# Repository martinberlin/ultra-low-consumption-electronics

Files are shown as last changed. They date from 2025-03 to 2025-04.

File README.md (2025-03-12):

# ultra-low-consumption-electronics
Here we will make electronic experiments to try reaching the lowest possible consumption when dealing with Microcontrollers and small Lithium batteries, turning when possible everything OFF

## Parts will be a shared folder between different PCBs

The parts folder will contain common Symbols, Footprints and 3D models.

## 1st. experiment: RV3032 application manual page 144

RV3032 is a DTCXO Temp. Compensated Real-Time Clock Module
Based on App. Manual released on May 2023 144/154 Rev. 1.3

**8.5. NO BACKUP SOURCE / EVENT INPUT USED ("WAKE-UP" & "POWER SWITCH")**

#f03c15WARNING:#f03c15
 This are theoretical ideas that could mainly be untested. Use any of them on production at your own risk.

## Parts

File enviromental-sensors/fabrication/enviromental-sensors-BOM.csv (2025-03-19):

Designator | Footprint | Comment | JLCPCB Part #
J1 | USB_C_Receptacle_HRO_TYPE-C-31-M-12 | USB_C_Receptacle_USB2.0 | C165948
C2,C8,C7,C1 | C_0805_2012Metric | 10uF | C15850
Y1 | RV3032C7 | RV-3032-C7 | C5127802
R5 | R_0603_1608Metric | 1k | C21190
SW4,SW2,SW1 | C2845289_SW-SMD_4P-L5.2-W5.2-P3.70-LS6.4 | TC-0522C-1.7-160G | C2845289
U6 | SOT-89-3 | L78L33ACUTR | C14170
J3 | FH5210S05SH99_LCD | FH52-10S-0.5SH_99 | C598038
R2,R12,R8,R3 | R_0603_1608Metric | 5.1k | C23186
R1,R10,R7 | R_0603_1608Metric | 10K | C25804
Q1 | SOT-23 | AO3401A | C15127
U5 | Sensirion_SCD4x-1EP_10.1x10.1mm_P1.25mm_EP4.8x4.8mm | SCD40-D-R2 | C3659421
U4 | C3001660_SOT95P285X140-5N | AP22811 | C3001660
U2 | SOT-23-5 | RT9080 | C841192
R9 | R_0603_1608Metric | 2K | C22975
D1 | D_SOD-123 | Schottky | C8598
IC2 | C22399676_TPS2117-8N | TPS2117DRLR | C22399676
C3 | C_0402_1005Metric | 1uF | C162161
C4 | C_0402_1005Metric | 22pF | C5119318
SW3 | C5143621_KEY-SMD_TS24ZJ | K2-1806SQ-A2DW-04 | C19100323
C5 | C_0805_2012Metric | 100nF | C49678
R14 | R_0603_1608Metric | 0Ω | C21189
R4,R6 | R_0402_1005Metric | 10k | C4322213
J2 | S2BPHSM4TBLFSN | S2B-PH-SM4-TB_LF__SN_ | C295747
C9 | CP_EIA-3528-15_AVX-H | 100uF | C16133
R13 | R_0603_1608Metric | 0Ω | C21189
R11 | R_0603_1608Metric | 10k | C25804
U1 | SOT-666 | USBLC6-2P6 | C2827693
Q2 | TEMT6000X01 | TEMT6000X01 | C94098
J5 | SM04B-SRSS-TB_LF__SN_ | JST connector | C160404

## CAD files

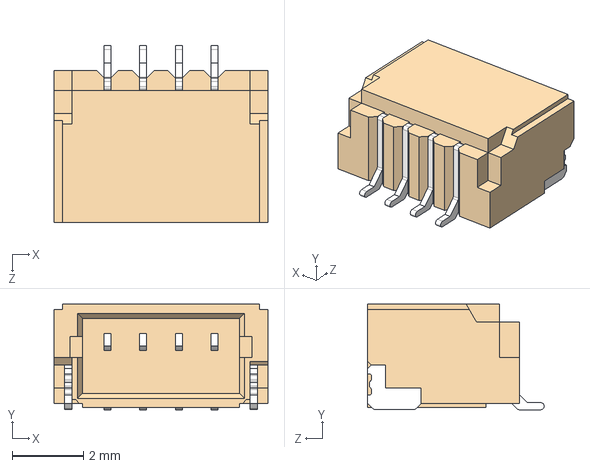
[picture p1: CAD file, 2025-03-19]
enviromental-sensors/parts/3D/QWIIC_SM04B-SRSS-TB_LF__SN_.stp
6.00 x 2.96 x 4.95 mm

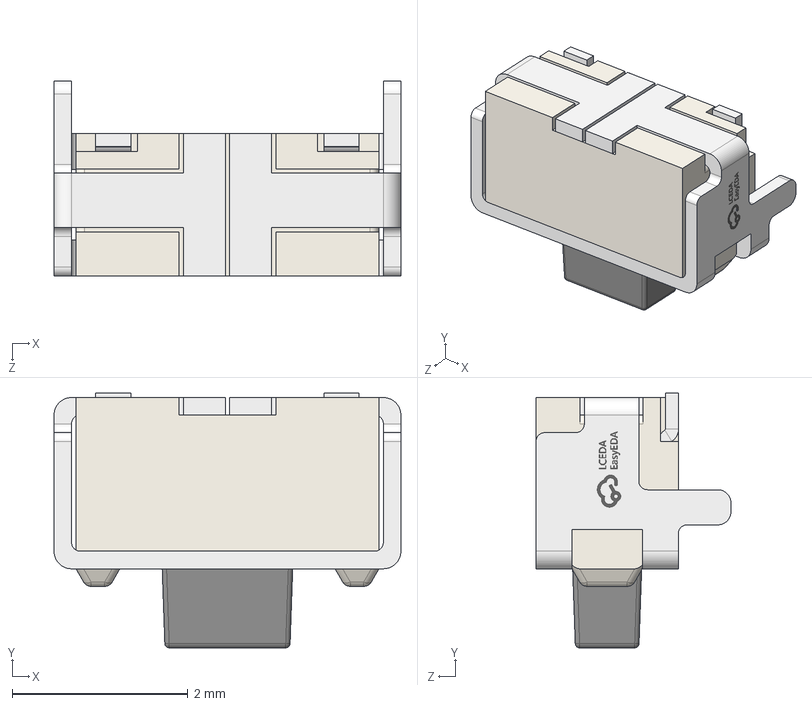
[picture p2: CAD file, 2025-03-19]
enviromental-sensors/parts/3D/KEY-SMD_K2_L4.0-W2.9-H1.6-P3.75.step
3.95 x 2.90 x 2.22 mm

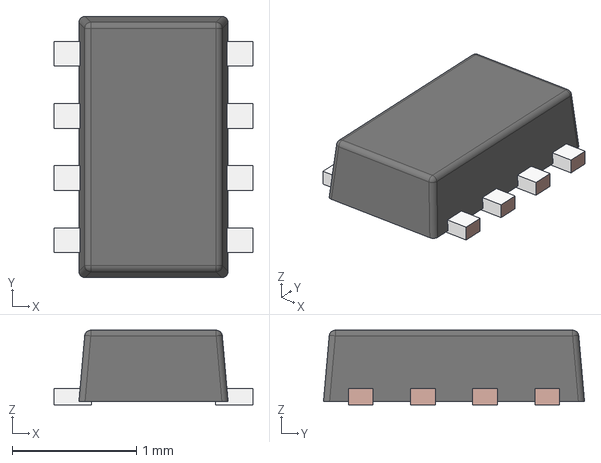
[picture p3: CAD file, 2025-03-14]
parts/3D/TPS2117DRLR.stp
1.60 x 2.10 x 0.6 mm
FRAME-DRL0008A
BODY-SOT

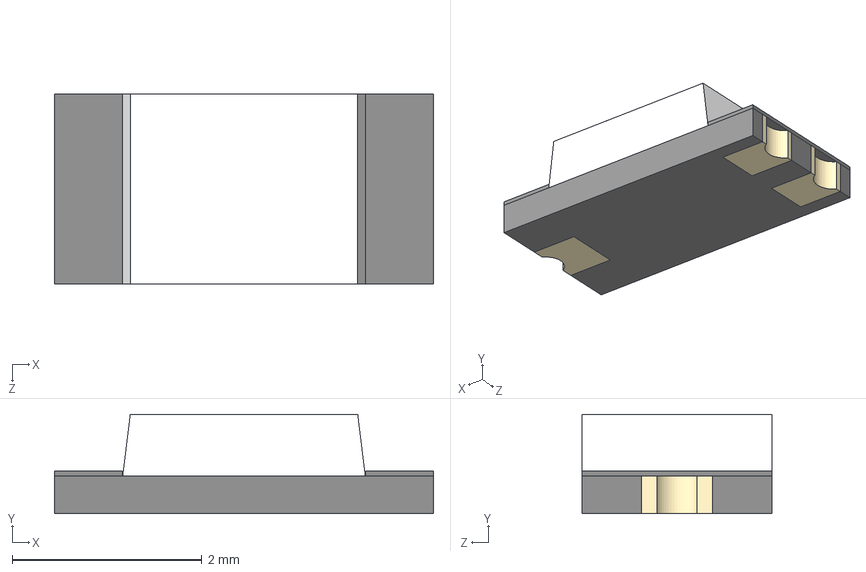
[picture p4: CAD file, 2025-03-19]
enviromental-sensors/parts/3D/TEMT6000X01.stp
4.00 x 1.05 x 2.00 mm

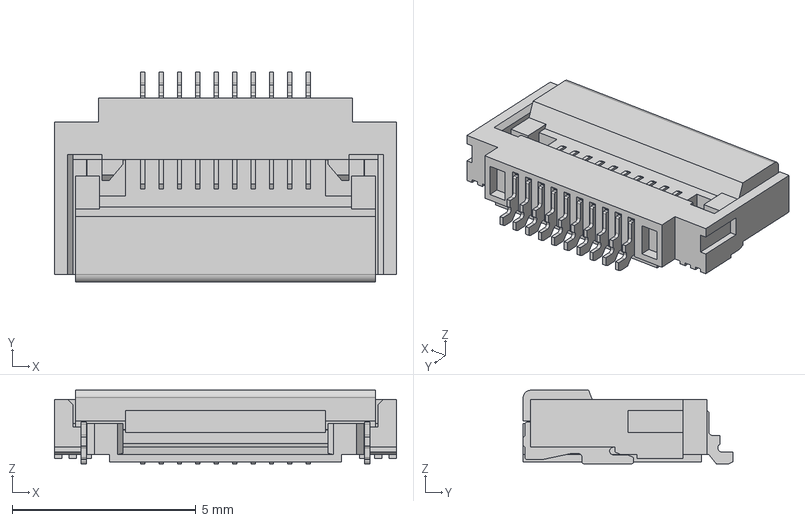
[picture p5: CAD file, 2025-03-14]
parts/3D/LCD-10S-0.5SH.step
9.30 x 5.70 x 2.00 mm

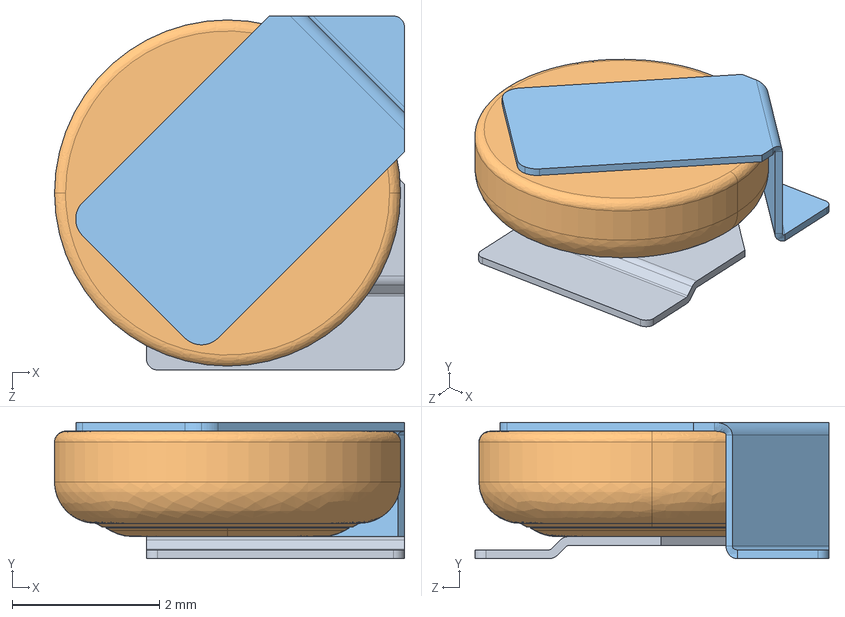
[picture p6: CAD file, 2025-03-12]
parts/3D/SuperCAP_XH414HG-IV01E.stp
4.75 x 1.85 x 4.80 mm

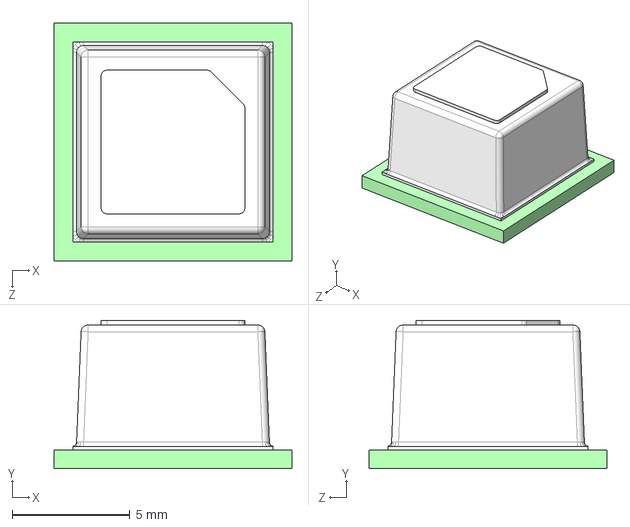
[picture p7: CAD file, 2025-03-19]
enviromental-sensors/parts/3D/SCD40-D-R2.stp
10.1 x 6.30 x 10.1 mm

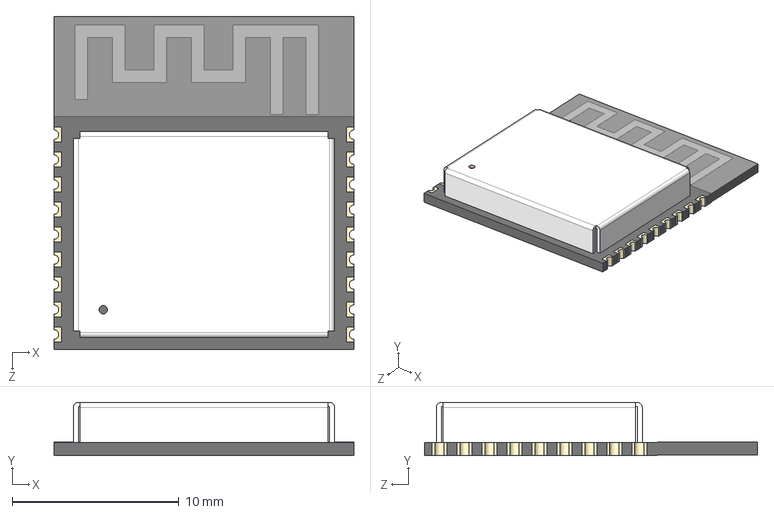
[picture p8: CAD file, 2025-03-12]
parts/3D/ESP32-C3-WROOM-02-N4.stp
18.0 x 3.20 x 20.0 mm

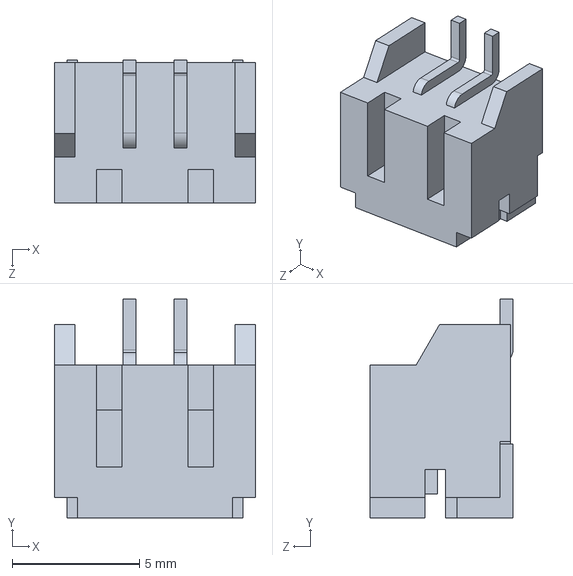
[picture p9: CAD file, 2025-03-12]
parts/3D/S2B-PH-SM4-TB_LF__SN_.stp
7.90 x 8.60 x 5.60 mm

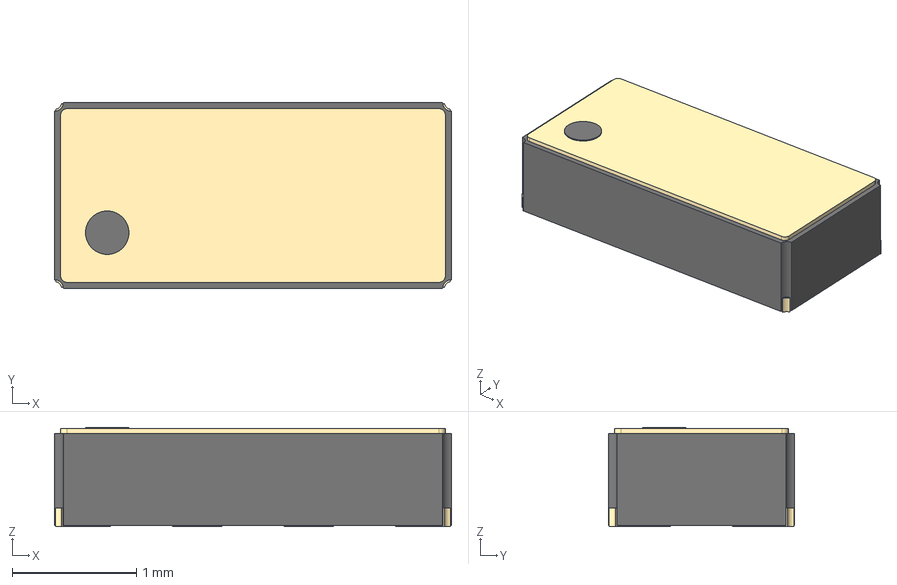
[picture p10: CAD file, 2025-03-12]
parts/3D/RV-3032-C7.stp
3.20 x 1.50 x 0.8 mm
Rect2
Rect3
Rect4
Rect5
Terminal

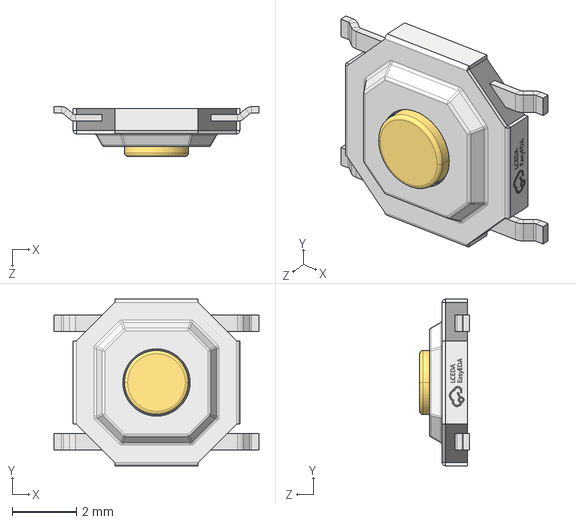
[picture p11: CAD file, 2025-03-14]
parts/3D/C2845289_KEY-SMD_4P-L5.2-W5.2-H1.5-LS6.4-P3.70.step
6.40 x 5.20 x 1.55 mm

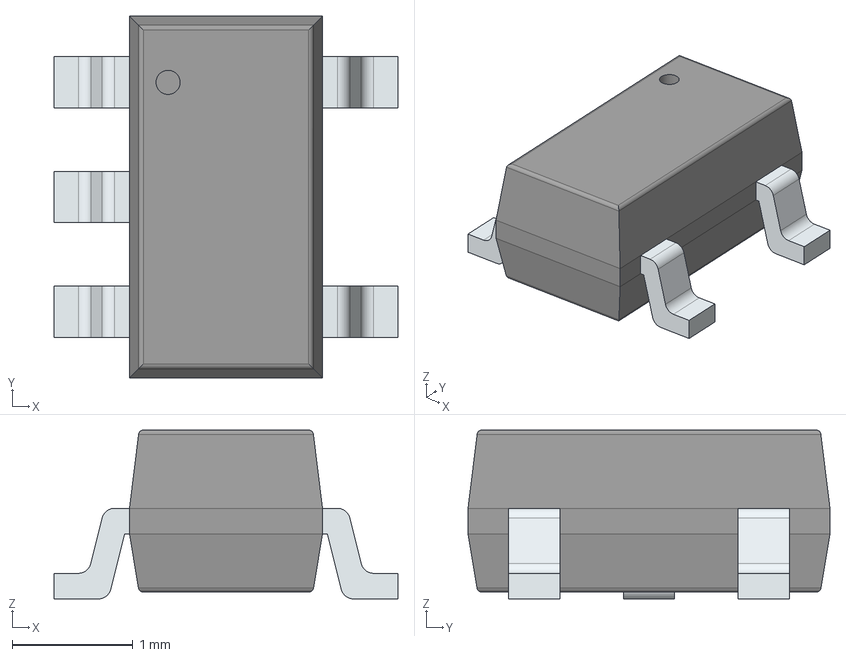
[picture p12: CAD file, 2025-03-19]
enviromental-sensors/parts/3D/C3001660_AP22811AW5-7.stp
2.85 x 3.00 x 1.40 mm
PinsArrayL
PinsArrayR

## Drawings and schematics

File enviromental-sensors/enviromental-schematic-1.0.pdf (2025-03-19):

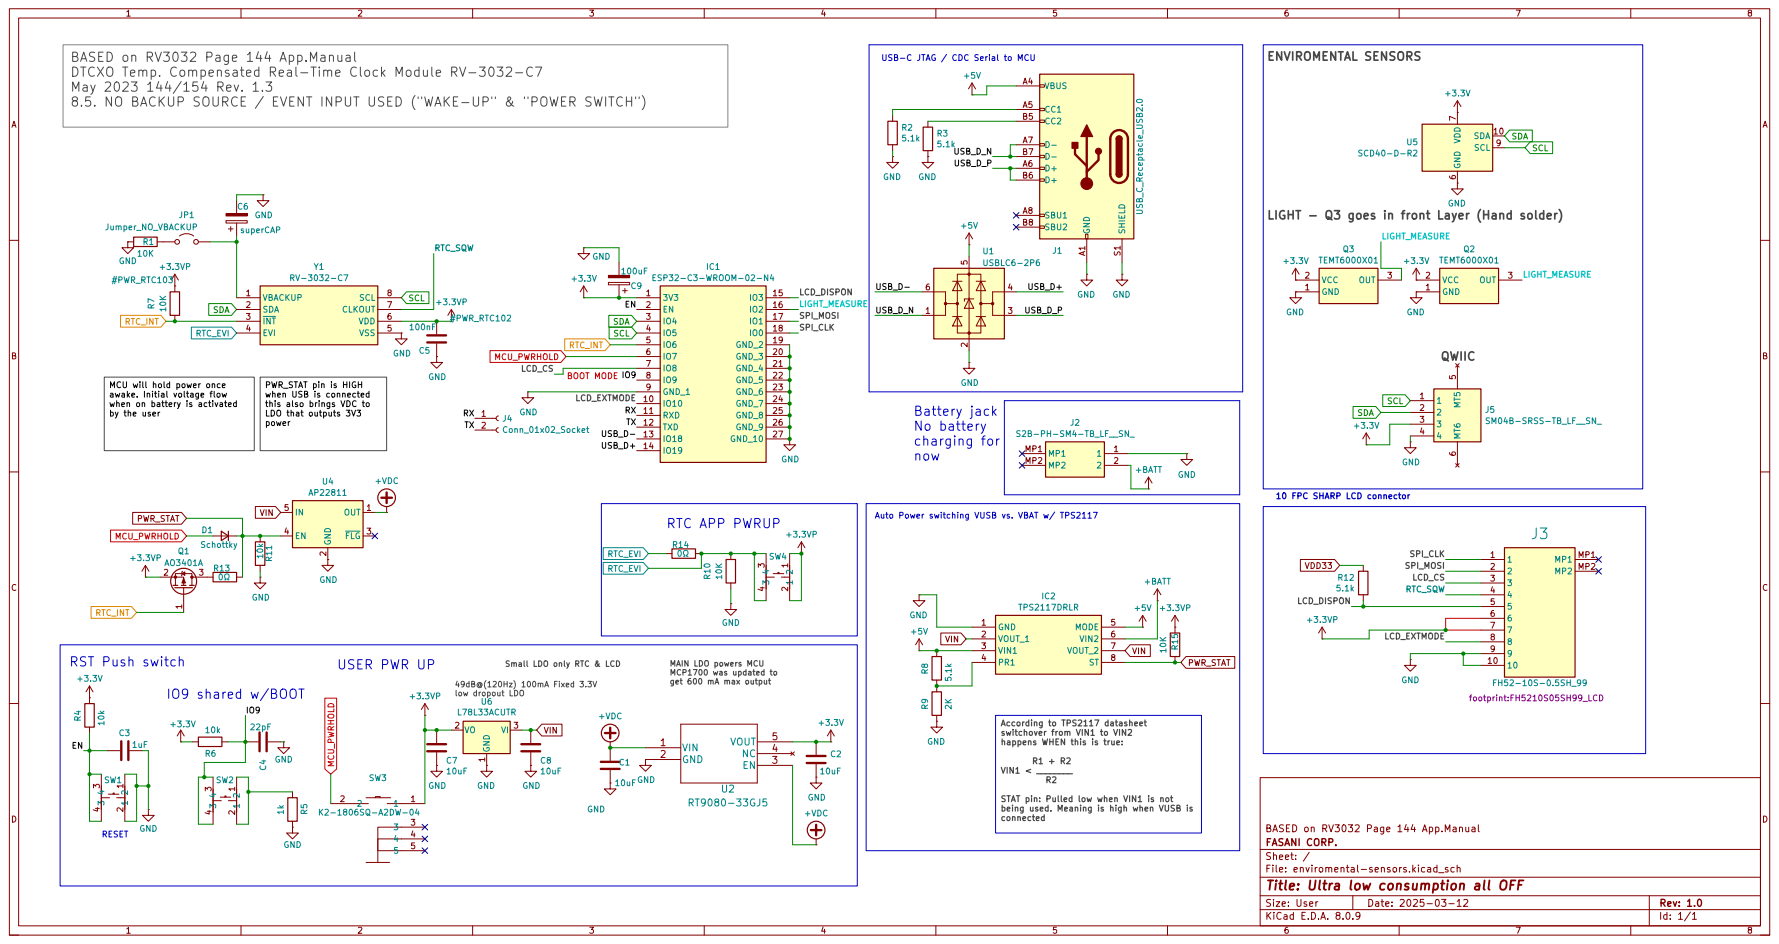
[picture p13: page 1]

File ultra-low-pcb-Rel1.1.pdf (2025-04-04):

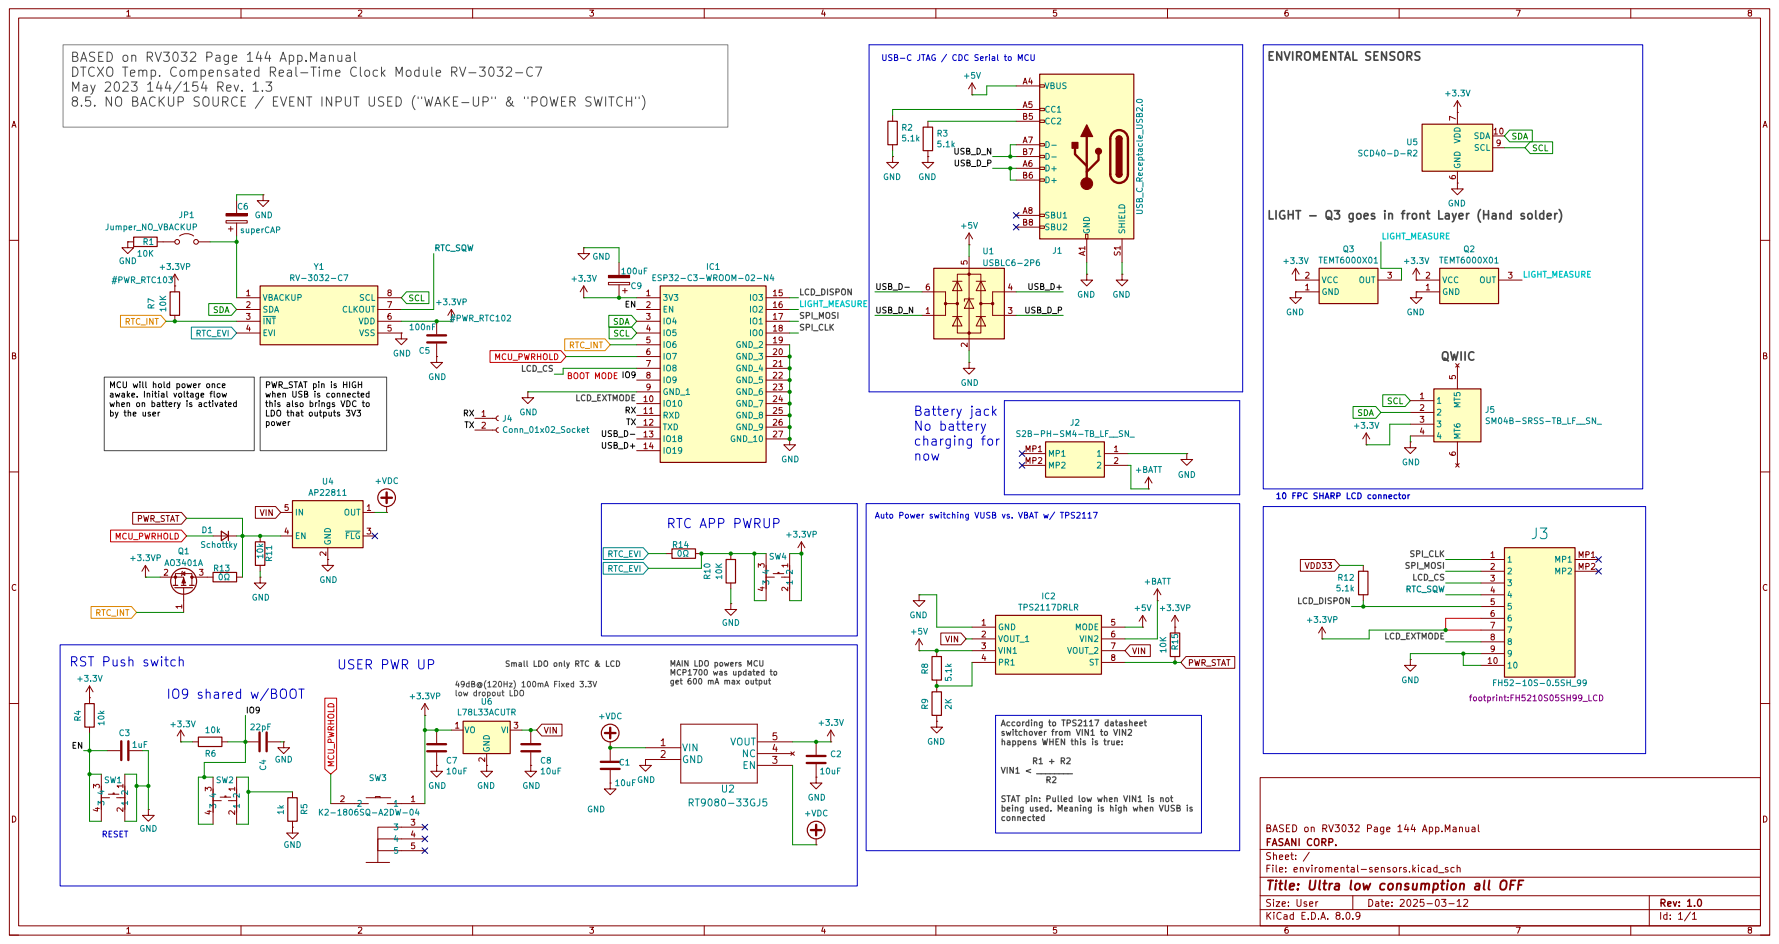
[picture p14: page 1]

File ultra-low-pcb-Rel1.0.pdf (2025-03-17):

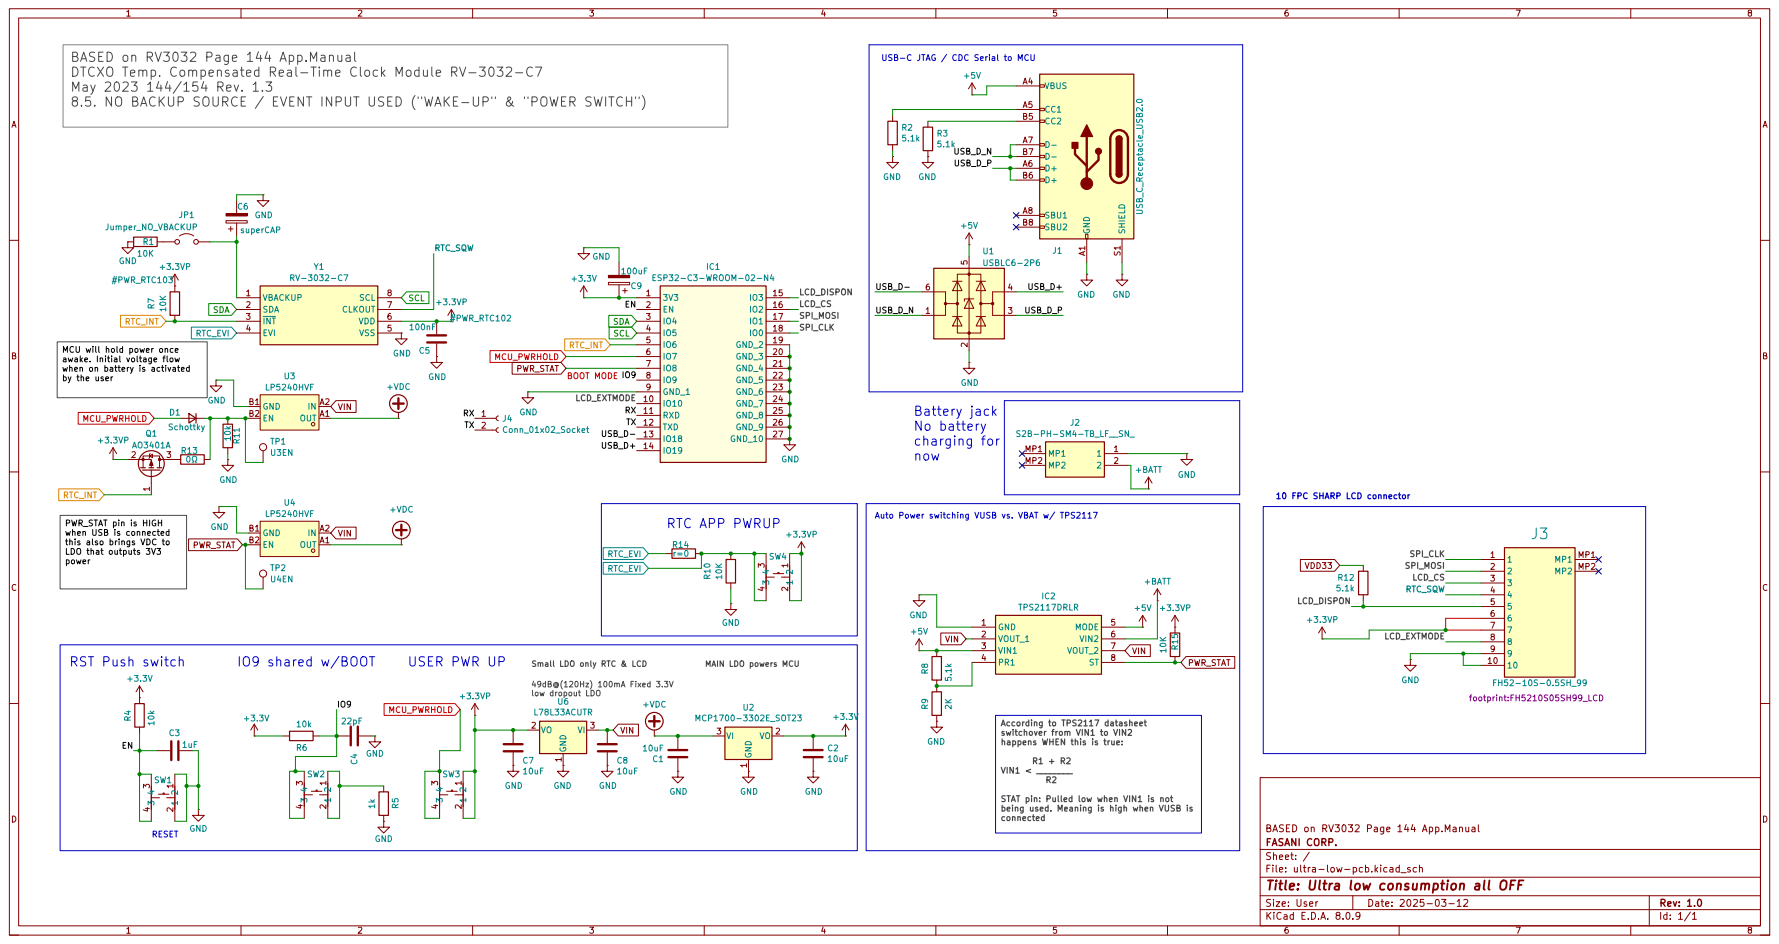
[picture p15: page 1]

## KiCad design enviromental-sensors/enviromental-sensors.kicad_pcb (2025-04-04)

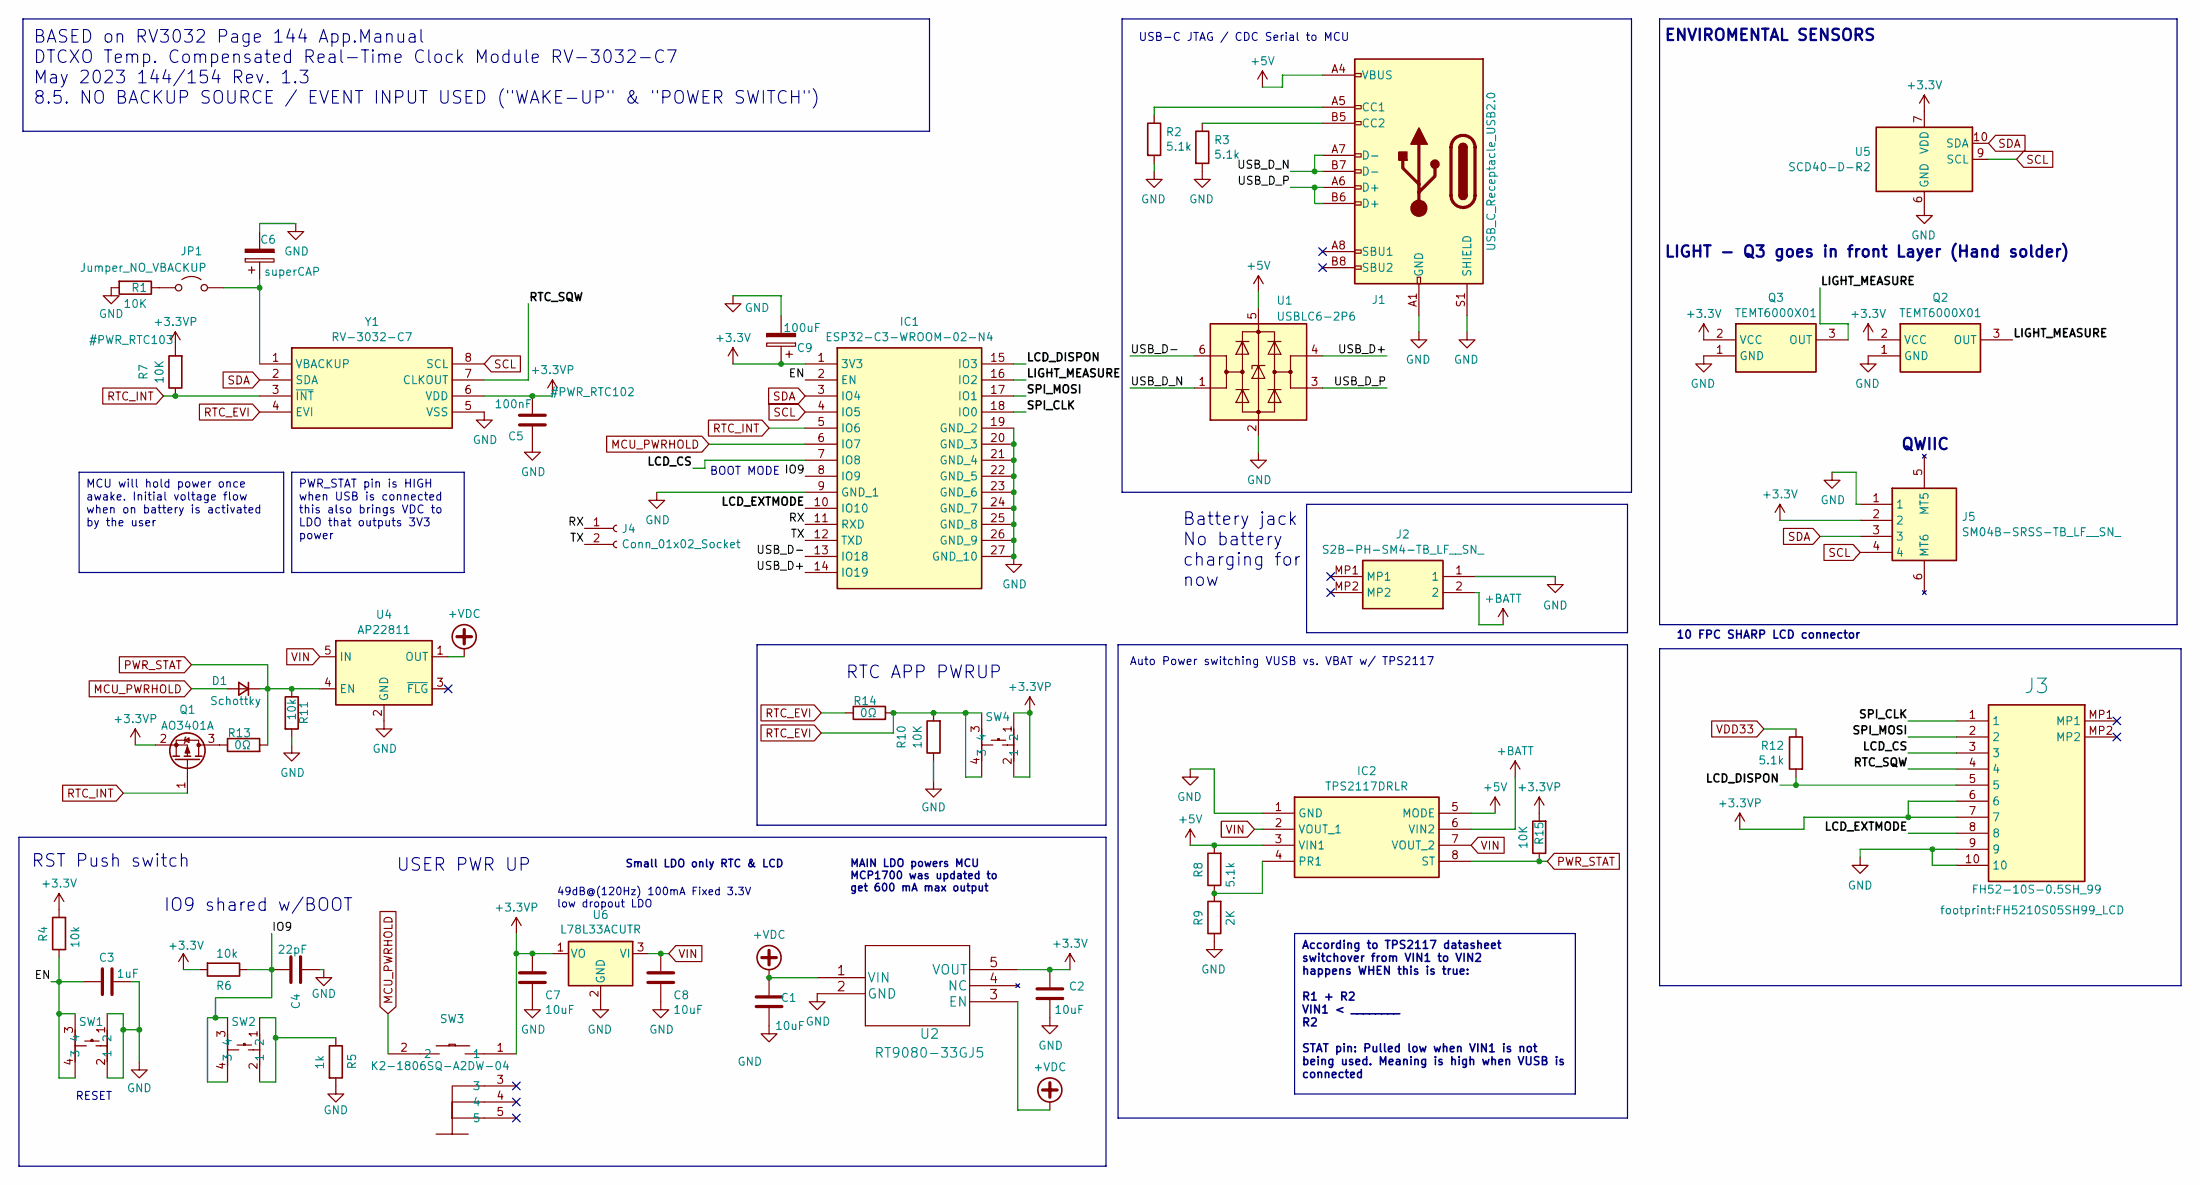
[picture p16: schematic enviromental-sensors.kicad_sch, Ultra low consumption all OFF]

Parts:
C1, C2, C7, C8: 10uF; C_0805_2012Metric; LCSC C15850
C3: 1uF; C_0402_1005Metric; LCSC C162161
C4: 22pF; C_0402_1005Metric; LCSC C5119318
C5: 100nF; C_0805_2012Metric; LCSC C49678
C6: superCAP; C9900013866_SUPERCAP-TH_XH414HG; LCSC C9900013866
C9: 100uF; CP_EIA-3528-15_AVX-H; LCSC C16133
D1: Schottky; D_SOD-123; LCSC C8598
IC1: ESP32-C3-WROOM-02-N4; ESP32C3WROOM02N4; LCSC C2934560
IC2: TPS2117DRLR; C22399676_TPS2117-8N; LCSC C22399676
J1: USB_C_Receptacle_USB2.0; USB_C_Receptacle_HRO_TYPE-C-31-M-12; LCSC C165948
J2: S2B-PH-SM4-TB_LF__SN_; S2BPHSM4TBLFSN; Manufacturer_Part_Number S2B-PH-SM4-TB(LF)(SN); LCSC C295747
J3: FH52-10S-0.5SH_99; FH5210S05SH99_LCD; Manufacturer_Part_Number FH52-10S-0.5SH(99); JLCPCB Part # C598038
J4: Conn_01x02_Socket; PinHeader_1x02_P2.54mm_Vertical
J5: SM04B-SRSS-TB_LF__SN_; QWIIC_SM04B-SRSS-TB_LFSN_; Manufacturer_Part_Number SM04B-SRSS-TB(LF)(SN); LCSC C160404
JP1: Jumper_NO_VBACKUP; SolderJumper-2_P1.3mm_Open_RoundedPad1.0x1.5mm
Q1: AO3401A; SOT-23; LCSC C15127
Q2, Q3: TEMT6000X01; LCSC C94098
R1, R7, R10, R15: 10K; R_0603_1608Metric; LCSC C25804
R2, R3, R8, R12: 5.1k; R_0603_1608Metric; LCSC C23186
R4, R6: 10k; R_0402_1005Metric; LCSC C4322213
R5: 1k; R_0603_1608Metric; LCSC C21190
R9: 2K; R_0603_1608Metric; LCSC C22975
R11: 10k; R_0603_1608Metric; LCSC C25804
R13: 0Ω; R_0603_1608Metric; LCSC C25804
R14: 0Ω; R_0603_1608Metric; LCSC C21189
SW1, SW2, SW4: TC-0522C-1.7-160G; C2845289_SW-SMD_4P-L5.2-W5.2-P3.70-LS6.4; LCSC Part C2845289
SW3: K2-1806SQ-A2DW-04; C5143621_KEY-SMD_TS24ZJ; LCSC Part C19100323
U1: USBLC6-2P6; SOT-666; LCSC C2827693
U2: RT9080-33GJ5; TSOT-23-5; LCSC C841192
U4: AP22811; C3001660_SOT95P285X140-5N; LCSC C3001660
U5: SCD40-D-R2; Sensirion_SCD4x-1EP_10.1x10.1mm_P1.25mm_EP4.8x4.8mm; LCSC C3659421
U6: L78L33ACUTR; SOT-89-3; LCSC C14170
Y1: RV-3032-C7; RV3032C7; LCSC C5127802

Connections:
+3.3V: C2.2, C9.1, IC1.1 (3V3), J5.2, Q2.2 (VCC), Q3.2 (VCC), R4.2, R6.2, U2.5 (VOUT), U5.7 (VDD), U5.19 (VDD)
+3.3VP: C5.1, C7.2, J3.6, J3.7, Q1.2 (S), R7.2, R15.2, SW3.1, SW4.1, SW4.2, U6.1 (VO), Y1.6 (VDD)
+5V: IC2.3 (VIN1), IC2.5 (MODE), J1.A4 (VBUS), J1.A9 (VBUS), J1.B4 (VBUS), J1.B9 (VBUS), R8.2, U1.5 (VBUS)
+BATT: IC2.6 (VIN2), J2.2
+VDC: C1.1, U2.1 (VIN), U2.3 (EN), U4.1 (OUT)
/EN: C3.2, IC1.2 (EN), R4.1, SW1.3, SW1.4
/IO9: C4.2, IC1.8 (IO9), R6.1, SW2.3, SW2.4
/LCD_CS: IC1.7 (IO8), J3.3
/LCD_DISPON: IC1.15 (IO3), J3.5, R12.2
/LCD_EXTMODE: IC1.10 (IO10), J3.8
/LIGHT_MEASURE: IC1.16 (IO2), Q2.3 (OUT), Q3.3 (OUT)
/RTC_SQW: J3.4, Y1.7 (CLKOUT)
/RX: IC1.11 (RXD), J4.1
/SPI_CLK: IC1.18 (IO0), J3.1
/SPI_MOSI: IC1.17 (IO1), J3.2
/TX: IC1.12 (TXD), J4.2
/USB_D+: IC1.14 (IO19), U1.4 (I/O2)
/USB_D-: IC1.13 (IO18), U1.6 (I/O1)
/USB_D_N: J1.A7 (D-), J1.B7 (D-), U1.1 (I/O1)
/USB_D_P: J1.A6 (D+), J1.B6 (D+), U1.3 (I/O2)
GND: C1.2, C2.1, C3.1, C4.1, C5.2, C6.2, C7.1, C8.1, C9.2, IC1.9 (GND_1), IC1.19 (GND_2), IC1.20 (GND_3), IC1.21 (GND_4), IC1.22 (GND_5), IC1.23 (GND_6), IC1.24 (GND_7), IC1.25 (GND_8), IC1.26 (GND_9), IC1.27 (GND_10), IC2.1 (GND), J1.A1 (GND), J1.A12 (GND), J1.B1 (GND), J1.B12 (GND), J1.S1 (SHIELD), J2.1, J3.9, J3.10, J5.1, Q2.1 (GND), Q3.1 (GND), R1.2, R2.2, R3.2, R5.2, R9.1, R10.1, R11.2, SW1.1, SW1.2, U1.2 (GND), U2.2 (GND), U4.2 (GND), U5.6 (GND), U5.20 (GND), U5.21 (GND), U6.2 (GND), Y1.5 (VSS)
MCU_PWRHOLD: D1.2 (A), IC1.6 (IO7), SW3.2
unnamed: IC2.4 (PR1), R8.1, R9.2
unnamed: J1.A5 (CC1), R2.1
unnamed: J1.B5 (CC2), R3.1
unnamed: JP1.1 (A), R1.1
unnamed: C6.1, JP1.2 (B), Y1.1 (VBACKUP)
unnamed: Q1.3 (D), R13.1
unnamed: R5.1, SW2.1, SW2.2
PWR_STAT: D1.1 (K), IC2.8 (ST), R11.1, R13.2, R15.1, U4.4 (EN)
RTC_EVI: R10.2, R14.1, R14.2, SW4.3, SW4.4, Y1.4 (EVI)
RTC_INT: IC1.5 (IO6), Q1.1 (G), R7.1, Y1.3 (~INT)
SCL: IC1.4 (IO5), J5.4, U5.9 (SCL), Y1.8 (SCL)
SDA: IC1.3 (IO4), J5.3, U5.10 (SDA), Y1.2 (SDA)
VDD33: R12.1
VIN: C8.2, IC2.2 (VOUT_1), IC2.7 (VOUT_2), U4.5 (IN), U6.3 (VI)

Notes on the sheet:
MCU will hold power once awake. Initial voltage flow when on battery is activated by the user
BASED on RV3032 Page 144 App.Manual DTCXO Temp. Compensated Real-Time Clock Module RV-3032-C7 May 2023 144/154 Rev. 1.3 8.5. NO BACKUP SOURCE / EVENT INPUT USED ("WAKE-UP" & "POWER SWITCH")
PWR_STAT pin is HIGH when USB is connected this also brings VDC to LDO that outputs 3V3 power
According to TPS2117 datasheet switchover from VIN1 to VIN2 happens WHEN this is true: R1 + R2 VIN1 < ________ R2 STAT pin: Pulled low when VIN1 is not being used. Meaning is high when VUSB is connected
ENVIROMENTAL SENSORS
IO9 shared w/BOOT
USER PWR UP
USB-C JTAG / CDC Serial to MCU
RST Push switch
RESET
RTC APP PWRUP
Small LDO only RTC & LCD
49dB@(120Hz) 100mA Fixed 3.3V low dropout LDO
Auto Power switching VUSB vs. VBAT w/ TPS2117
Battery jack No battery charging for now
LIGHT - Q3 goes in front Layer (Hand solder)
QWIIC
BOOT MODE
10 FPC SHARP LCD connector
MAIN LDO powers MCU MCP1700 was updated to get 600 mA max output

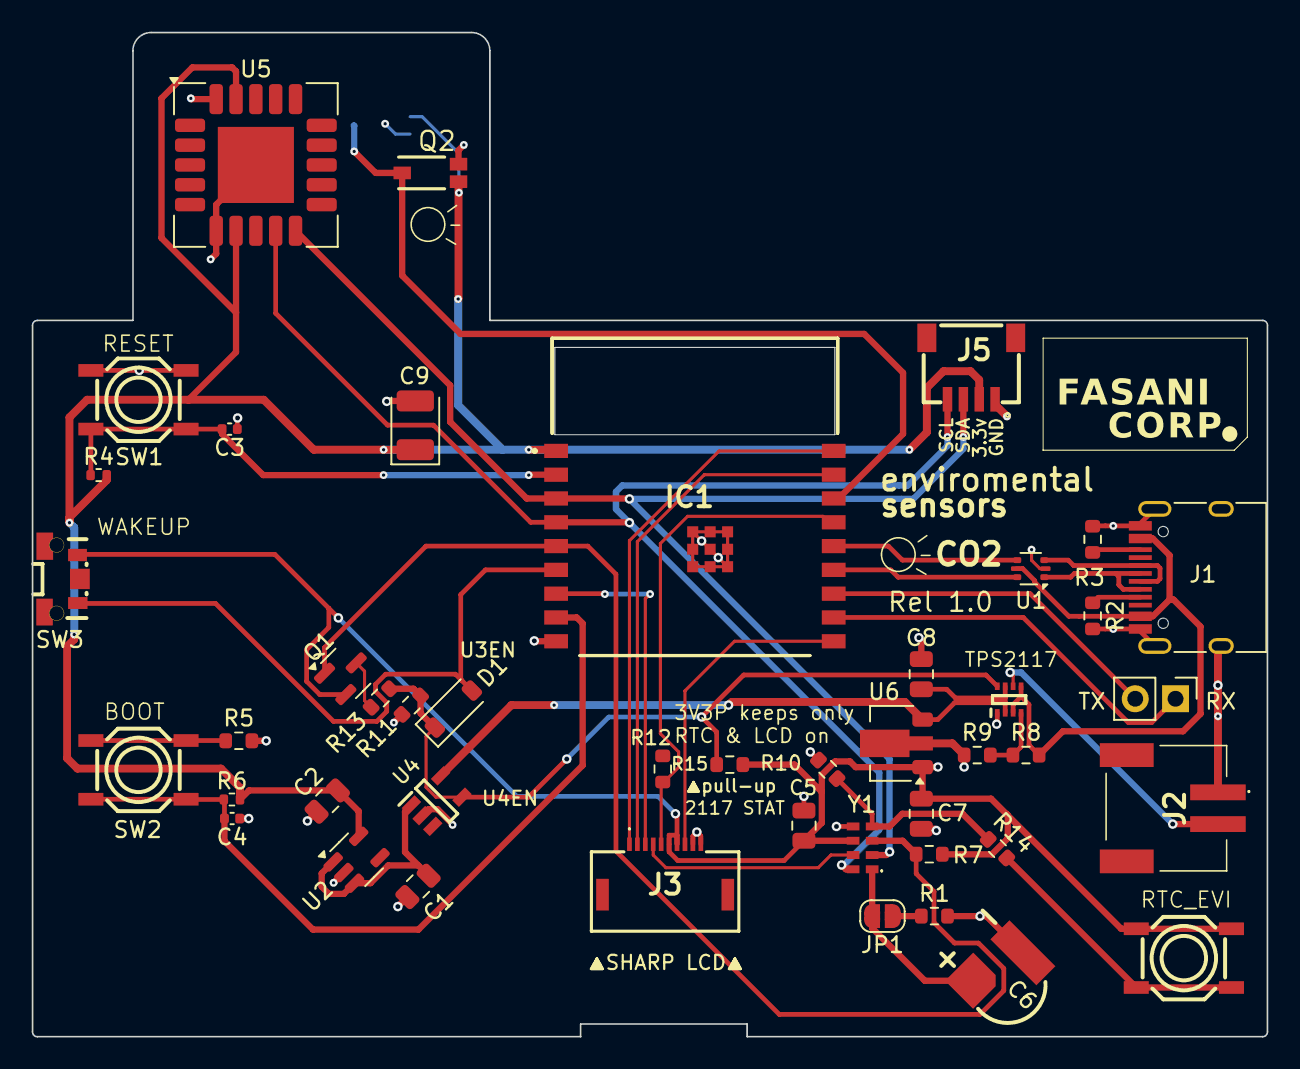
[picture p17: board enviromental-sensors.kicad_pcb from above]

Board: 2 copper layers, 77.9 x 63.3 mm, 46 parts (1 on the bottom side), 35 nets.

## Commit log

2025-03-12 Add SuperCAP to RTC
    [SuperCAP_XH414HG-IV01E.stp, ultra-low-pcb.kicad_sch]
2025-03-12 Update schematics
    [ultra-low-pcb.kicad_sch]
2025-03-13 Correct C5
    [ultra-low-pcb.kicad_sch]
2025-03-13 Add EVI app PWR up
    [ultra-low-pcb.kicad_sch]
2025-03-14 1.0 passes DRC
    [C2845289_KEY-SMD_4P-L5.2-W5.2-H1.5-LS6.4-P3.70.step, LCD-10S-0.5SH.step, TPS2117DRLR.stp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]
2025-03-15 Update U3
    [ultra-low-pcb.kicad_pcb, ultra-low-pcb.kicad_sch]
2025-03-15 Correct Q1. Thanks Syl!
    [ultra-low-pcb.kicad_pcb, ultra-low-pcb.kicad_sch]
2025-03-15 Put some love in silk
    [ultra-low-pcb.kicad_pcb]
2025-03-17 Last revision before 1.0
    [ultra-low-pcb.kicad_pcb, ultra-low-pcb.kicad_sch]
2025-03-17 Update SCH
    [ultra-low-pcb.kicad_sch]
2025-03-19 Add env. sensors PCB
    [C3001660_AP22811AW5-7.stp, KEY-SMD_K2_L4.0-W2.9-H1.6-P3.75.step, QWIIC_SM04B-SRSS-TB_LF__SN_.stp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]
2025-04-04 1.0 fixes: QWIIC corrected (note 1.0 release before this commit is unfixed)
    [enviromental-sensors.kicad_pcb, enviromental-sensors.kicad_sch]
